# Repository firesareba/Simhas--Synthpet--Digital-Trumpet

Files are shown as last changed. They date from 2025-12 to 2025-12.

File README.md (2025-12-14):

## **Digital Trumpet - Valve-Based MIDI Wind Controller**

A fully functional digital trumpet using valve buttons and octave selection, displaying real-time note information on a 0.96" OLED screen with audio output through a built-in amplifier. Perfect for your desk!

## **Inspiration**

I love music and I play the trumpet so I wanted to be able to take that kind of sound into the digital world. This uses accurate trumpet fingerings with added octave buttons

## **Challenges**

I had to learn new software, EasyEDA and Onshape which was difficult. But i LOVE THEM now.

THANKS HACK CLUB!

## **Specifications**

| No. | Quantity | Designator | Footprint | Value | Manufacturer Part | Manufacturer | Supplier Part | Supplier | LCSC Price | JLCPCB Price | Primary Category | Secondary Category | Pin Count | LCSC Stock | JLCPCB Stock | Mounting Style | Layer |
|---|---|---|---|---|---|---|---|---|---|---|---|---|---|---|---|---|---|
| 1 | 17 | C1,C2,C7,C8,C9,C11,C12,C13,C14,C15,C16,C17,C18,C19,C20,C21,C23 | C0805 | 100nF | CC0805KRX7R9BB104 | YAGEO(国巨) | C49678 | LCSC |  | 0.0007 | Capacitors | Multilayer Ceramic Capacitors MLCC - SMD/SMT | 2 |  | 9620872 | SMT | T |
| 2 | 2 | C3,C4 | C0402 | 22pF | 0402CG220J500NT | FH(风华) | C1555 | LCSC |  | 0.0002 | Capacitors | Multilayer Ceramic Capacitors MLCC - SMD/SMT | 2 |  | 2013915 | SMT | T |
| 3 | 2 | C5,C6 | C0805 | 10uF | CL21A106KAYNNNE | SAMSUNG(三星) | C15850 | LCSC |  | 0.0014 | Capacitors | Multilayer Ceramic Capacitors MLCC - SMD/SMT | 2 |  | 11048581 | SMT | T |
| 4 | 2 | C10,C22 | C0805 | 1uF | CL21B105KBFNNNE | SAMSUNG(三星) | C28323 | LCSC |  | 0.0013 | Capacitors | Multilayer Ceramic Capacitors MLCC - SMD/SMT | 2 |  | 7404801 | SMT | T |
| 5 | 2 | C24,C25 | CAP-TH_BD6.3-P2.50-D1.0-FD | 220uF | KM227M016E11RR0VH2FP0 | Chengx(承兴) | C43349 | LCSC |  | 0.0032 | Capacitors | Aluminum Electrolytic Capacitors - Leaded | 2 |  | 223698 | DIP | T |
| 6 | 2 | Q1,Q2 | SOT-23-3_L2.9-W1.3-P1.90-LS2.4-BR |  | MMBT5551(RANGE:200-300) | CJ(江苏长电/长晶) | C2145 | LCSC |  | 0.0017 | Transistors/Thyristors | Bipolar (BJT) | 3 |  | 3542439 | SMT | T |
| 7 | 2 | R1,R2 | R0805 | 5.1kΩ | 0805W8F5101T5E | UNI-ROYAL(厚声) | C27834 | LCSC |  | 0.0003 | Resistors | Chip Resistor - Surface Mount | 2 |  | 4904293 | SMT | T |
| 8 | 12 | R3,R4,R5,R6,R7,R8,R9,R10,R11,R12,R13,R14 | R0805 | 10kΩ | 0805W8F1002T5E | UNI-ROYAL(厚声) | C17414 | LCSC |  | 0.0003 | Resistors | Chip Resistor - Surface Mount | 2 |  | 29504279 | SMT | T |
| 9 | 1 | R15 | R0805 | 1kΩ | 0805W8F1001T5E | UNI-ROYAL(厚声) | C17513 | LCSC |  | 0.0003 | Resistors | Chip Resistor - Surface Mount | 2 |  | 11865611 | SMT | T |
| 10 | 1 | R16 | RES-ADJ-TH_RK09L1140A5P | 10kΩ | RK09L114001T | ALPSALPINE(阿尔卑斯阿尔派) | C470463 | LCSC |  | 0.1888 | Resistors | Potentiometers, Variable Resistors | 5 |  | 1978 | DIP | T |
| 11 | 1 | SPK1 | SPK-TH_BD23.0-P10.00-D0.8-L-RD |  | GSPK2307P-8R1W | INGHAi(赢海) | C530531 | LCSC |  | 0.1119 | Audio Products / Vibration Motors | Speakers | 2 |  | 4263 | DIP | T |
| 12 | 9 | SW1,SW2,SW3,SW4,SW5,SW6,SW7,SW8,SW9 | SW-SMD_4P-L5.1-W5.1-P3.70-LS6.5-TL_H1.5 |  | TS-1187A-B-A-B | XKB Connection(中国星坤) | C318884 | LCSC |  | 0.0027 | Switches | Tactile Switches | 4 |  | 721279 | SMT | T |
| 13 | 1 | U1 | SOP-16_L10.0-W3.9-P1.27-LS6.0-BL |  | CH340C | WCH(南京沁恒) | C84681 | LCSC |  | 0.0744 | Interface | USB Converters | 16 |  | 10582 | SMT | T |
| 14 | 1 | U2 | SOT-223-3_L6.5-W3.4-P2.30-LS7.0-BR |  | AMS1117-3.3 | AMS | C6186 | LCSC |  | 0.0227 | Power Management (PMIC) | Voltage Regulators - Linear, Low Drop Out (LDO) Regulators | 4 |  | 962381 | SMT | T |
| 15 | 1 | U3 | WIFI-SMD_ESP32-WROOM-32E |  | ESP32-WROOM-32E-N4 | ESPRESSIF(乐鑫) | C701341 | LCSC |  | 0.5028 | IoT/Communication Modules | WiFi Modules | 47 |  | 19208 | SMT | T |
| 16 | 1 | U4 | OLED-TH_L27.8-W27.2-P2.54_C9900033791 |  | HS96L03W2C03 | HS(汉昇) | C5248080 | LCSC |  | 0.2816 | Displays | OLED Display | 4 |  | 7452 | DIP | T |
| 17 | 1 | U5 | MSOP-8_L3.0-W3.0-P0.65-LS5.0-BL |  | PAM8302AASCR | DIODES(美台) | C113367 | LCSC |  | 0.0249 | Amplifiers/Comparators | Audio Amplifiers | 8 |  | 15387 | SMT | T |
| 18 | 1 | U6 | AUDIO-TH_PJ-320A-4P-DIP |  | PJ-320A-4P DIP | SHOU HAN(首韩) | C18185602 | LCSC |  | 0.007 | Connectors | Audio Connectors | 4 |  | 10640 | DIP | T |
| 19 | 1 | USBC1 | USB-C_SMD-TYPE-C-31-M-12_1 |  | TYPE-C-31-M-12 | 韩国韩荣 | C165948 | LCSC |  | 0.0242 | Connectors | USB Connectors | 16 |  | 241717 | DIP | T |
| THE FOLLOWING ARE NOT INCLUDED IN THE STRUCTURE OF THE ABOVE BOM, AND ARE MEANT FOR OTHER PARTS OF THE PROJECT | QTY | NAME | PRICE | LINK |  |  |  |  |  |  |  |  |  |  |  |  |  |
| 20 | 4 | M2 SCREWS | 4.91 | https://www.aliexpress.us/item/3256807088271853.html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"order"%3A"968"%2C"eval"%3A"1"%2C"fromPage"%3A"search"%7D&pdp_npi=6%40dis%21USD%215.18%214.91%21%21%215.18%214.91%21%402101c44f17657398024198653efc3b%2112000040030168809%21sea%21US%213031952535%21X%211%210%21n_tag%3A-29919%3Bd%3A99553acd%3Bm03_new_user%3A-29895&curPageLogUid=ZOU9OMfbvggj&utparam-url=scene%3Asearch%7Cquery_from%3A%7Cx_object_id%3A1005007274586605%7C_p_origin_prod%3A&search_p4p_id=202512141116423606091713891360001620195_2 |  |  |  |  |  |  |  |  |  |  |  |  |  |
| 21 | 1 | 3D PRINTED CASE ALL PCS | ~$5-$10 | #printing-legion |  |  |  |  |  |  |  |  |  |  |  |  |  |

## **Wiring and Schematic**

The circuit uses USB-C for power and programming, I2C interface for the OLED, nine active-LOW buttons with pull-ups and debounce caps, and the ESP32's built-in DAC for audio generation through a Class-D amplifier.

## **Visuals**









## **Getting Started**

1. Flash Firmware: Connect USB-C cable, the auto-reset circuit will automatically enter bootloader mode when uploading.
2. Test Buttons: Verify all nine buttons register correctly on the OLED display.
3. Audio Check: Press sound enable (SW9) and test valve combinations across all octave ranges.
4. Volume Adjustment: Turn the potentiometer to set comfortable listening level.

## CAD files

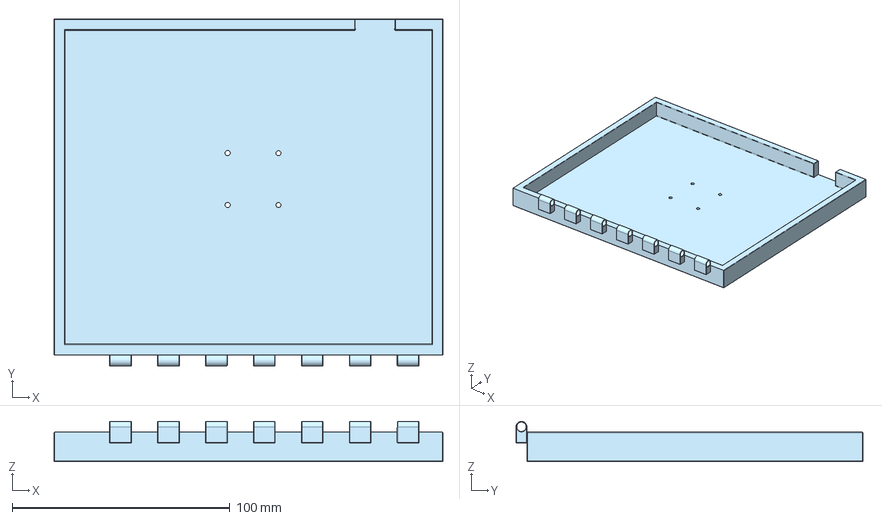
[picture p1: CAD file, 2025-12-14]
cad/Main.step
178.5 x 159.3 x 18.5 mm

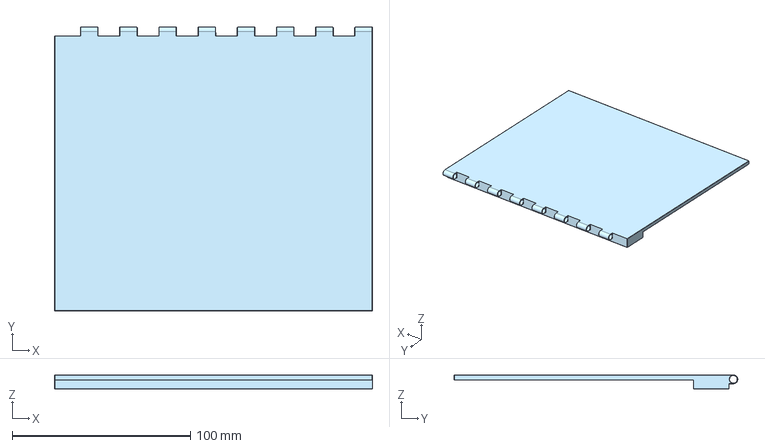
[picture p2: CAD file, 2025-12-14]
cad/Lid.step
178.5 x 159.3 x 8.00 mm

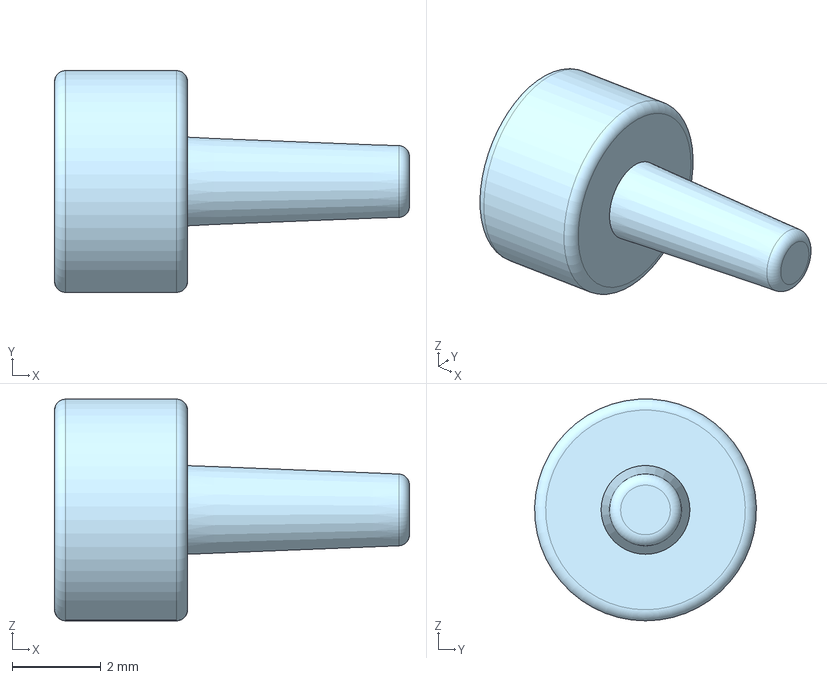
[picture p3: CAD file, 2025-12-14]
cad/Cap.step
8.00 x 5.00 x 5.00 mm

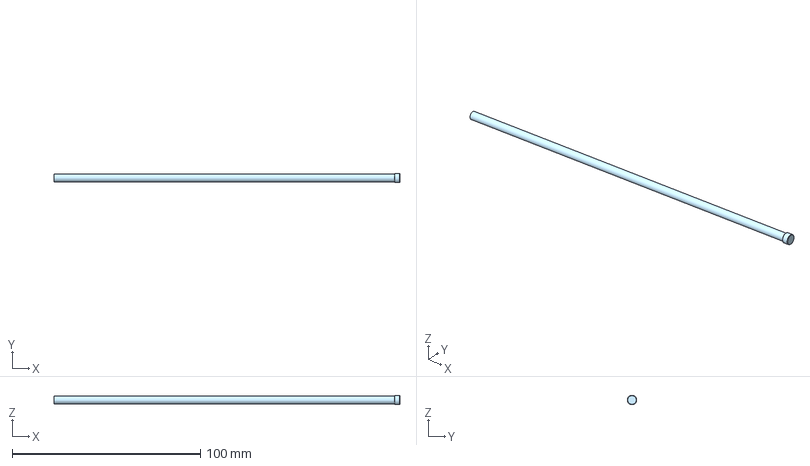
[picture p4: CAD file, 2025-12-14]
cad/Cog.step
184.0 x 5.00 x 5.00 mm

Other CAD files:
cad/Full Case.x_t

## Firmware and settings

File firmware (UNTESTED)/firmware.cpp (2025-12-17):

#include <Arduino.h>
#include <Wire.h>
#include <Adafruit_GFX.h>
#include <Adafruit_SSD1306.h>
#include <driver/dac.h>

#define VALVE1_PIN 19    
#define VALVE2_PIN 21    
#define VALVE3_PIN 22    

#define OCTAVE1_PIN 18   
#define OCTAVE2_PIN 5    
#define OCTAVE3_PIN 17   
#define OCTAVE4_PIN 16   
#define OCTAVE5_PIN 4    

#define SOUND_EN_PIN 15  
#define DAC_PIN 25      

#define SCREEN_WIDTH 128
#define SCREEN_HEIGHT 64
#define OLED_RESET -1
#define SCREEN_ADDRESS 0x3C
Adafruit_SSD1306 display(SCREEN_WIDTH, SCREEN_HEIGHT, &Wire, OLED_RESET);

#define SAMPLE_RATE 44100
hw_timer_t *timer = NULL;
volatile float currentFrequency = 0.0;
volatile float phase = 0.0;
volatile bool soundEnabled = false;

struct TrumpetNote {
  const char* noteName;
  int fingering;      
  const char* octaveButton;
  float frequency;
};

const TrumpetNote FINGERING_CHART[] = {
  {"F#3", 0, "None", 185.0},
  {"G3", 23, "None", 196.0},
  {"G#3", 13, "None", 207.7},
  {"A3", 12, "None", 220.0},
  {"A#3", 1, "None", 233.1},
  {"B3", 2, "None", 246.9},
  {"C4", 0, "None", 261.6},
  

  {"C#4", 0, "SW4", 277.2},
  {"D4", 23, "SW4", 293.7},
  {"D#4", 13, "SW4", 311.1},
  {"E4", 12, "SW4", 329.6},
  {"F4", 1, "SW4", 349.2},
  {"F#4", 2, "SW4", 370.0},
  {"G4", 0, "SW4", 392.0},
  

  {"G#4", 23, "SW5", 415.3},
  {"A4", 13, "SW5", 440.0},
  {"A#4", 12, "SW5", 466.2},
  {"B4", 1, "SW5", 493.9},
  {"C5", 2, "SW5", 523.3},
  

  {"C#5", 0, "SW6", 554.4},
  {"D5", 13, "SW6", 587.3},
  {"D#5", 12, "SW6", 622.3},
  {"E5", 1, "SW6", 659.3},
  

  {"F5", 0, "SW7", 698.5},
  {"F#5", 2, "SW7", 740.0},
  {"G5", 0, "SW7", 784.0},
  
  
  {"G#5", 23, "SW8", 830.6},
  {"A5", 13, "SW8", 880.0},
  {"A#5", 12, "SW8", 932.3},
  {"B5", 1, "SW8", 987.8},
  {"C6", 2, "SW8", 1047.0}
};

const int CHART_SIZE = sizeof(FINGERING_CHART) / sizeof(TrumpetNote);


int getFingeringCode(bool v1, bool v2, bool v3) {
  if (!v1 && !v2 && !v3) return 0;    
  if (!v1 && !v2 && v3) return 3;      
  if (!v1 && v2 && !v3) return 2;   
  if (v1 && !v2 && !v3) return 1;   
  if (!v1 && v2 && v3) return 23;    
  if (v1 && !v2 && v3) return 13;     
  if (v1 && v2 && !v3) return 12;    
  if (v1 && v2 && v3) return 123;    
  return 0;
}


const char* getOctaveButtonName(int octave) {
  switch(octave) {
    case 0: return "None"; 
    case 1: return "SW4";   
    case 2: return "SW5";   
    case 3: return "SW6";   
    case 4: return "SW7";   
    case 5: return "SW8";   
    default: return "None";
  }
}


const TrumpetNote* findNote(int fingeringCode, const char* octaveButton) {
  for (int i = 0; i < CHART_SIZE; i++) {
    if (FINGERING_CHART[i].fingering == fingeringCode && 
        strcmp(FINGERING_CHART[i].octaveButton, octaveButton) == 0) {
      return &FINGERING_CHART[i];
    }
  }
  return nullptr;
}


void IRAM_ATTR onTimer() {
  if (soundEnabled && currentFrequency > 0) {
   
    float phaseIncrement = (2.0 * PI * currentFrequency) / SAMPLE_RATE;
    phase += phaseIncrement;
    if (phase >= 2.0 * PI) {
      phase -= 2.0 * PI;
    }
    
    
    float sineValue = sin(phase);
    uint8_t dacValue = (uint8_t)((sineValue + 1.0) * 127.5);
    
 
    dac_output_voltage(DAC_CHANNEL_1, dacValue);
  } else {

    dac_output_voltage(DAC_CHANNEL_1, 128);
    phase = 0.0;
  }
}

void setup() {
  Serial.begin(115200);
  Serial.println("Digital Trumpet Starting...");
  Serial.println("Using accurate fingering chart from CSV");
  
 
  pinMode(VALVE1_PIN, INPUT_PULLUP);
  pinMode(VALVE2_PIN, INPUT_PULLUP);
  pinMode(VALVE3_PIN, INPUT_PULLUP);
  

  pinMode(OCTAVE1_PIN, INPUT_PULLUP);
  pinMode(OCTAVE2_PIN, INPUT_PULLUP);
  pinMode(OCTAVE3_PIN, INPUT_PULLUP);
  pinMode(OCTAVE4_PIN, INPUT_PULLUP);
  pinMode(OCTAVE5_PIN, INPUT_PULLUP);
  

  pinMode(SOUND_EN_PIN, INPUT_PULLUP);
  

  Wire.begin(23, 32);
  

  if(!display.begin(SSD1306_SWITCHCAPVCC, SCREEN_ADDRESS)) {
    Serial.println(F("SSD1315 allocation failed"));
  } else {
    Serial.println("SSD1315 OLED initialized");
  }
  
  display.clearDisplay();
  display.setTextSize(2);
  display.setTextColor(SSD1306_WHITE);
  display.setCursor(10, 10);
  display.println("Digital");
  display.println(" Trumpet");
  display.setTextSize(1);
  display.setCursor(10, 50);
  display.println("CSV Chart");
  display.display();
  delay(2000);
  

  dac_output_enable(DAC_CHANNEL_1);
  dac_output_voltage(DAC_CHANNEL_1, 128); 
  
  
  timer = timerBegin(0, 80, true); 
  timerAttachInterrupt(timer, &onTimer, true);
  timerAlarmWrite(timer, 1000000 / SAMPLE_RATE, true);
  timerAlarmEnable(timer);
  
  Serial.println("Setup complete!");
  Serial.println("Loaded " + String(CHART_SIZE) + " notes from fingering chart");
  Serial.println("Octave Ranges:");
  Serial.println("No button: F#3-C4 (LOWEST)");
  Serial.println("SW4: C#4-G4");
  Serial.println("SW5: G#4-C5");
  Serial.println("SW6: C#5-E5");
  Serial.println("SW7: F5-G5");
  Serial.println("SW8: G#5-C6 (HIGHEST)");
}

void loop() {

  bool valve1 = !digitalRead(VALVE1_PIN);
  bool valve2 = !digitalRead(VALVE2_PIN);
  bool valve3 = !digitalRead(VALVE3_PIN);
  

  int octave = 0; 
  if (!digitalRead(OCTAVE1_PIN)) octave = 1;
  else if (!digitalRead(OCTAVE2_PIN)) octave = 2; 
  else if (!digitalRead(OCTAVE3_PIN)) octave = 3; 
  else if (!digitalRead(OCTAVE4_PIN)) octave = 4;
  else if (!digitalRead(OCTAVE5_PIN)) octave = 5;
  

  soundEnabled = !digitalRead(SOUND_EN_PIN);
  

  int fingeringCode = getFingeringCode(valve1, valve2, valve3);
  

  const char* octaveButton = getOctaveButtonName(octave);
  

  const TrumpetNote* note = findNote(fingeringCode, octaveButton);
  
  if (note != nullptr) {
  
    currentFrequency = note->frequency;
    
   
    display.clearDisplay();
    
  
    display.setTextSize(3);
    display.setTextColor(SSD1306_WHITE);
    display.setCursor(15, 5);
    display.println(note->noteName);
    
  
    display.setTextSize(1);
    display.setCursor(0, 35);
    display.print("Freq: ");
    display.print(note->frequency, 1);
    display.println(" Hz");
    
   
    display.setCursor(0, 46);
    display.print("Octave: ");
    display.println(note->octaveButton);
    
    
    display.setCursor(0, 56);
    display.print("V:");
    display.print(valve1 ? "1" : "-");
    display.print(valve2 ? "2" : "-");
    display.print(valve3 ? "3" : "-");
    display.print(" [");
    display.print(fingeringCode);
    display.print("]");
    
 
    display.setCursor(90, 56);
    display.print(soundEnabled ? "ON" : "OFF");
    
    display.display();
    
   
    Serial.print("Note: ");
    Serial.print(note->noteName);
    Serial.print(" | Freq: ");
    Serial.print(note->frequency, 2);
    Serial.print(" Hz | Fingering: ");
    Serial.print(fingeringCode);
    Serial.print(" | Octave: ");
    Serial.print(octaveButton);
    Serial.print(" | Sound: ");
    Serial.println(soundEnabled ? "ON" : "OFF");
    
  } else {
   
    currentFrequency = 0.0;
    
    display.clearDisplay();
    display.setTextSize(2);
    display.setCursor(10, 10);
    display.println("Invalid");
    display.println("Combo");
    
    display.setTextSize(1);
    display.setCursor(0, 46);
    display.print("F:");
    display.print(fingeringCode);
    display.print(" O:");
    display.println(octaveButton);
    display.display();
    
    Serial.print("ERROR: No note for fingering ");
    Serial.print(fingeringCode);
    Serial.print(" with octave ");
    Serial.println(octaveButton);
  }
  
  delay(50);
}

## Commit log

2025-12-14 Initialize README for Digital Trumpet project
    Added detailed project description, specifications, wiring, visuals, and getting started instructions for the Digital Trumpet project.
2025-12-17 Format and clean up pin definitions in firmware.cpp
